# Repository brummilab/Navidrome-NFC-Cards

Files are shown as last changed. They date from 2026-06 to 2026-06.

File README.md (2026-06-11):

# Navidrome NFC Cards

Selbstgebaute Toniebox: NFC-Karte antippen → Musik vom eigenen [Navidrome](https://www.navidrome.org/)-Server läuft sofort.

Inspiriert von [gelly-nfc](https://github.com/Fingel/gelly-nfc), aber direkt gegen die Subsonic-API gebaut – ohne Desktop-Player, läuft headless auf dem Raspberry Pi.

---

## Architektur

```
┌──────────────────────────┐        Subsonic API        ┌─────────────────────┐
│      Raspberry Pi        │ ◄────────────────────────► │  Navidrome          │
│                          │                             │  (TrueNAS, NAS, …)  │
│  ┌────────────────────┐  │                             └─────────────────────┘
│  │  ACR1252U          │  │
│  │  NFC-Reader (USB)  │  │
│  └─────────┬──────────┘  │
│            │ Karte tippen │
│            ▼             │
│  ┌─────────────────────┐ │
│  │  NFC-Daemon         │─┼──► mpv ──► Lautsprecher
│  └─────────────────────┘ │
│  ┌─────────────────────┐ │
│  │  Web-UI  :8080      │ │  ← Karten verwalten
│  └─────────────────────┘ │
└──────────────────────────┘
```

---

## Hardware

| Teil | Modell |
|---|---|
| Einplatinen-Computer | Raspberry Pi 3 Model B (oder neuer) |
| NFC-Reader | [ACR1252U](https://www.acs.com.hk/en/products/342/acr1252u-usb-nfc-reader-iii-nfc-forum-certified-reader/) USB NFC Reader III |
| NFC-Karten | NTAG215 oder NTAG213 (ISO 14443-3A) |
| Lautsprecher | 3,5-mm-Klinke oder USB am Pi |
| Musik-Server | Navidrome (separat, z. B. auf TrueNAS) |

---

## Funktionsweise

Eine Karte kann auf zwei Arten einem Album / Track zugewiesen werden:

### A) Karte direkt beschreiben *(empfohlen)*

Der Text `album:abc123` wird als NDEF-Record direkt auf den Chip geschrieben.  
→ Karte ist **selbst-beschreibend**, kein DB-Eintrag nötig, kompatibel mit [gelly-nfc](https://github.com/Fingel/gelly-nfc).

### B) UID-Mapping via Web-UI

Die Karten-UID wird in einer lokalen SQLite-Datenbank einem Navidrome-Eintrag zugeordnet.  
→ Karte muss **nicht** beschrieben werden.

Beim Antippen wird immer zuerst **A** versucht, dann **B**.

---

## Installation

### 1. System-Pakete

```bash
sudo apt update
sudo apt install pcscd libpcsclite-dev mpv git python3-pip python3-venv
sudo systemctl enable --now pcscd
```

### 2. User-Rechte für NFC-Reader

```bash
sudo usermod -aG plugdev $USER
newgrp plugdev   # oder neu einloggen
```

### 3. Projekt einrichten

```bash
git clone https://github.com/brummilab/navidrome-nfc-cards.git
cd navidrome-nfc-cards

python3 -m venv .venv
source .venv/bin/activate
pip install -r requirements.txt
```

### 4. Konfiguration

```bash
cp config.example.yaml config.yaml
nano config.yaml
```

Mindest-Konfiguration:

```yaml
navidrome:
  url: http://192.168.1.100:4533   # IP des Navidrome-Servers
  username: dein-user
  password: dein-passwort
```

### 5. Starten

```bash
# Terminal 1 – Web-UI  →  http://raspberrypi:8080
python -m src.web.app

# Terminal 2 – NFC-Daemon
python -m src.run_daemon
```

---

## Erste Karte beschreiben

```bash
# 1. Reader prüfen
python -m src.card_writer list-readers
# [0] ACS ACR1252 Dual Reader PICC 0

# 2. Navidrome-Album-ID herausfinden
#    → Navidrome Web-UI öffnen → Album anklicken → URL ablesen:
#    http://navidrome:4533/app/#/album/abc123def456
#                                        ^^^^^^^^^^^^^ das ist die ID

# 3. Karte beschreiben (Reader anschließen, Karte drauflegen)
python -m src.card_writer write "album:abc123def456"

# 4. Inhalt prüfen
python -m src.card_writer read-ndef
# UID:  AA:BB:CC:DD
# NDEF: album:abc123def456
```

Unterstützte Typen:

```bash
python -m src.card_writer write "album:<id>"
python -m src.card_writer write "track:<id>"
python -m src.card_writer write "playlist:<id>"
python -m src.card_writer write "artist:<id>"
```

---

## Web-UI

`http://raspberrypi:8080`

| Seite | Funktion |
|---|---|
| **Karten** | Übersicht aller UID-Mappings mit Cover |
| **Scannen** | Karte antippen → UID anzeigen |
| **Musik** | Navidrome durchsuchen, UID per Klick zuweisen |

---

## Autostart (systemd)

```bash
# Daemon-Service
sudo tee /etc/systemd/system/navidrome-nfc-daemon.service > /dev/null << 'EOF'
[Unit]
Description=Navidrome NFC Daemon
After=network.target pcscd.service

[Service]
User=pi
WorkingDirectory=/home/pi/navidrome-nfc-cards
ExecStart=/home/pi/navidrome-nfc-cards/.venv/bin/python -m src.run_daemon
Restart=on-failure
RestartSec=5

[Install]
WantedBy=multi-user.target
EOF

# Web-UI-Service
sudo tee /etc/systemd/system/navidrome-nfc-web.service > /dev/null << 'EOF'
[Unit]
Description=Navidrome NFC Web-UI
After=network.target

[Service]
User=pi
WorkingDirectory=/home/pi/navidrome-nfc-cards
ExecStart=/home/pi/navidrome-nfc-cards/.venv/bin/python -m src.web.app
Restart=on-failure
RestartSec=5

[Install]
WantedBy=multi-user.target
EOF

sudo systemctl enable --now navidrome-nfc-daemon
sudo systemctl enable --now navidrome-nfc-web
```

---

## Gehäuse (3D-Druck)

Im Ordner `design/` liegt eine parametrische [OpenSCAD](https://openscad.org/)-Datei für ein Gehäuse im Toniebox-Stil:

- **Unterteil** ([`design/unterteil.stl`](design/unterteil.stl)): reader-breit (103 × 67 mm). Pi 180° gedreht, USB-Seite mit 10 mm Abstand zur Wand – genug Platz, damit das feste USB-Kabel des NFC-Readers komplett im Gehäuse an einen USB-Port des Pi angeschlossen werden kann (kein Wanddurchbruch dafür nötig). Einziger Wanddurchbruch: Stromanschluss in der Rückwand fürs Pi-Netzteil. Lüftungsschlitze links und rechts (je 4 Stück), läuft über WLAN. Pi auf 4 Abstandshaltern (M2.5).
- **Deckel** ([`design/deckel.stl`](design/deckel.stl)): gleichmäßig breit (108 × 72 mm), hält den ACR1252U *face-up* in einer Mulde. Der Reader ruht auf einer umlaufenden Neck-Auflage-Leiste, das Dach hält ihn nach oben. Karte oben drauflegen → NFC liest durch 1,5 mm Dach. Ein Kabel-Kanal an einer Ecke der Reader-Mulde führt das feste USB-Kabel des Readers nach unten ins Gehäuseinnere zum Pi. Der Deckel stülpt sich mit einem Rock 9 mm über das Unterteil.

Maße nach Datenblatt:

| Teil | Maß |
|---|-----|
| ACR1252U | 98 × 65 × 12,8 mm |
| Pi 3B Platine | 85 × 56 mm |
| Pi Montagelöcher | Rechteck 58 × 49 mm, 3,5 mm vom Rand (M2.5) |

### Dateien

| Datei | Zweck |
|---|---|
| `design/unterteil.stl` · `design/deckel.stl` | **Druckfertig** – direkt in den Slicer laden |
| `design/gehaeuse.scad` | Parametrische Quelle (OpenSCAD) |
| `design/build_stl.py` | STL neu erzeugen ohne OpenSCAD (`pip install numpy scipy trimesh manifold3d`) |
| `design/DRUCKANLEITUNG.md` | Schritt-für-Schritt-Anleitung für den **Bambu Lab P1S** |

> **Wichtig:** Der Deckel wird mit dem **Dach nach unten** gedruckt (Details in der Druckanleitung) – sonst wäre Support nötig.

### Zusammenbau

1. **Pi einsetzen**: Raspberry Pi **180° gedreht** (USB-Ports zeigen nach links, 10 mm Platz zur Wand) mit 4× M2.5-Schrauben auf die Abstandshalter schrauben.
2. **Reader einlegen**: ACR1252U von unten in die Deckel-Mulde legen (Geräteoberseite Richtung Dach). Der Reader ruht auf der umlaufenden Neck-Leiste, das Dach hält ihn nach oben. Das feste USB-Kabel durch den Kabel-Kanal an der Mulden-Ecke nach unten ins Gehäuseinnere führen.
3. **Kabel anschließen**: Im Inneren das USB-Kabel des Readers in einen USB-Port des Pi einstecken (Platz dafür ist links neben dem Pi).
4. **Schließen**: Deckel über das Unterteil stülpen – der Rock greift 9 mm über die Wände und zentriert alles. Das Stromkabel des Pi durch den Durchbruch in der Rückwand anschließen.

**Karte abspielen:** NFC-Karte oben auf den Deckel legen – der Reader liest durch das 1,5 mm dünne Dach (Lesedistanz lt. Datenblatt bis 50 mm).

---

## Docker (alternativ)

```bash
cp config.example.yaml config.yaml
docker compose up -d
```

> Der `reader`-Service benötigt USB-Zugriff (`privileged: true` in `docker-compose.yml`).  
> Auf dem Raspberry Pi ist das native Setup unkomplizierter.

---

## Konfigurationsreferenz

| Option | Standard | Beschreibung |
|---|---|---|
| `navidrome.url` | – | URL des Navidrome-Servers |
| `navidrome.username` | – | Benutzername |
| `navidrome.password` | – | Passwort |
| `playback.mode` | `mpv` | `mpv` = lokal auf Pi · `jukebox` = serverseitig |
| `playback.mpv_options` | `[]` | z. B. `["--volume=80"]` |
| `nfc.reader_index` | `0` | Index des Readers (siehe `list-readers`) |
| `nfc.debounce_seconds` | `5` | Selbe Karte nicht öfter als alle X Sekunden triggern |
| `web.port` | `8080` | Port der Web-UI |
| `data.db_path` | `data/mappings.db` | Pfad zur SQLite-Datenbank |

Umgebungsvariablen überschreiben `config.yaml`:  
`NAVIDROME_URL` · `NAVIDROME_USERNAME` · `NAVIDROME_PASSWORD` · `WEB_SECRET_KEY`

---

## Projektstruktur

```
src/
  config.py        Config-Loader (YAML + Env-Vars)
  navidrome.py     Subsonic API Client
  mappings.py      SQLite UID-Mapping
  player.py        Wiedergabe via mpv oder Jukebox
  nfc_reader.py    NFC-Daemon (CardMonitor, event-driven)
  card_writer.py   CLI: UIDs lesen, NDEF schreiben/lesen
  run_daemon.py    Entry Point Daemon
  web/
    app.py         Flask Web-UI
    templates/     Jinja2 Templates (Bootstrap 5)
design/
  gehaeuse.scad    3D-Druck Gehäuse (OpenSCAD)
```

---

## Abhängigkeiten

| Paket | Zweck |
|---|---|
| `pyscard` | PC/SC Zugriff auf den NFC-Reader |
| `ndeflib` | NDEF Record Encoding/Decoding |
| `flask` | Web-UI |
| `requests` | Navidrome Subsonic API |
| `pyyaml` | Konfigurationsdatei |
| `mpv` *(System)* | Lokale Audio-Wiedergabe |
| `pcscd` *(System)* | PC/SC Daemon |

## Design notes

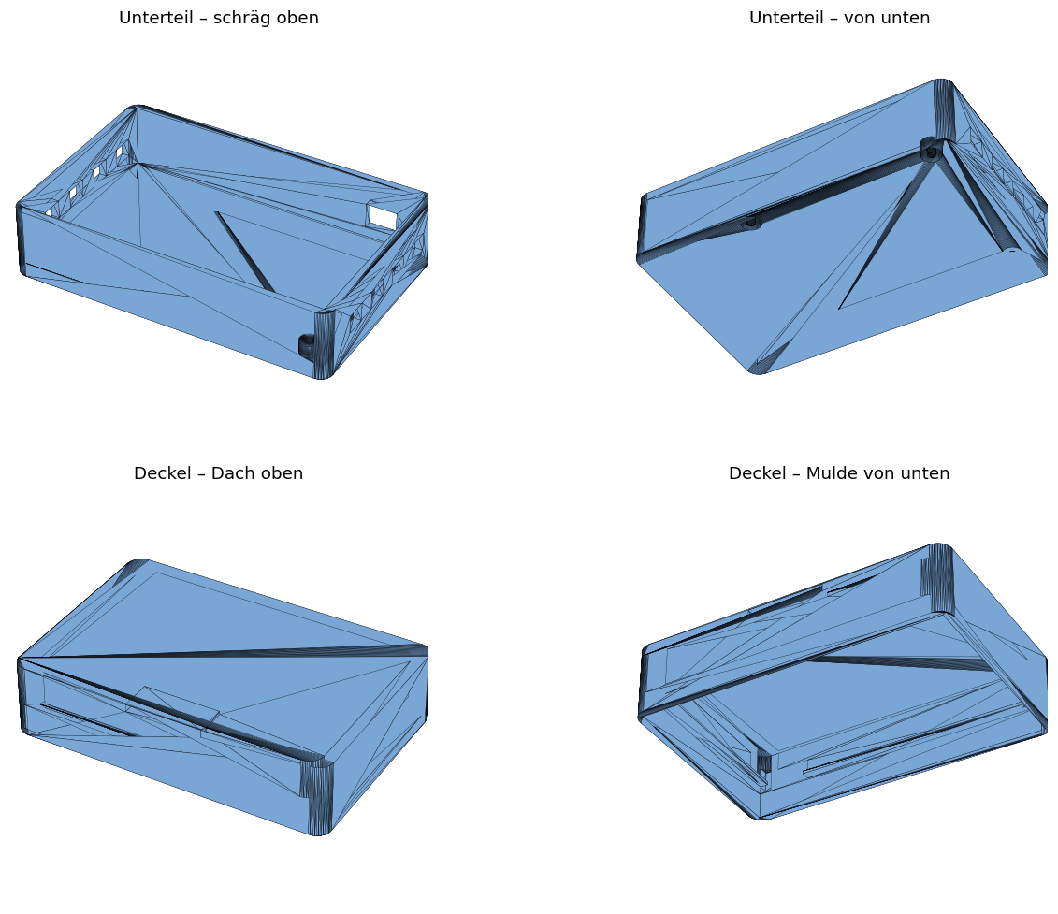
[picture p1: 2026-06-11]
design/preview.png

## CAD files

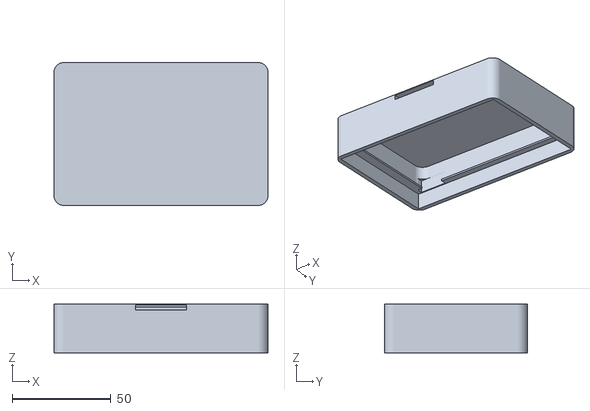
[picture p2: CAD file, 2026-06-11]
design/deckel.stl
108.4 x 72.4 x 24.8

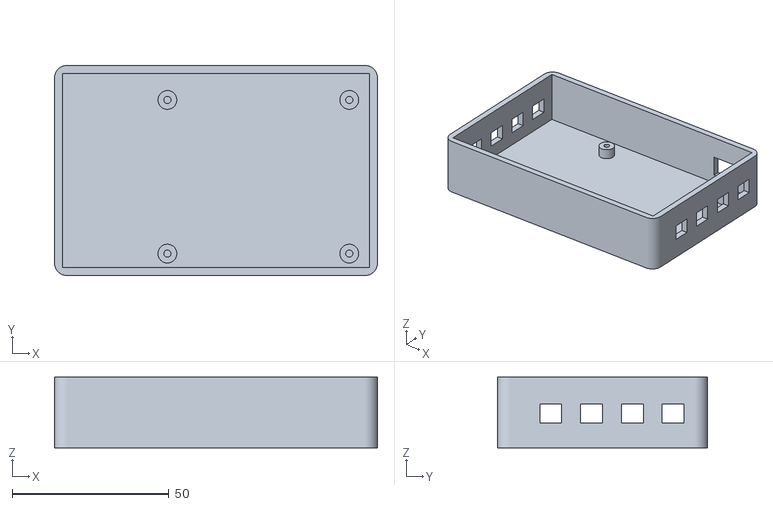
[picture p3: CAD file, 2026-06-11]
design/unterteil.stl
103.0 x 67.0 x 22.5

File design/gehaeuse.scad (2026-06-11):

// ============================================================
//  Navidrome NFC Box  ·  v7
//  Raspberry Pi 3 Model B (v1.2)  +  ACR1252U NFC-Reader
// ============================================================
//  Konzept (Toniebox-Stil):
//    · Unterteil : Breite = Reader-Breite → gleichmäßige Optik.
//                  Pi zentriert auf Abstandshaltern, Anschlüsse
//                  liegen bündig an den Wänden.
//    · Deckel    : Gleich breit wie Unterteil (nur kleiner Rand-
//                  Überstand wie ein klassischer Deckel). Hält den
//                  ACR1252U face-up in einer Mulde. Reader ruht auf
//                  einer umlaufenden Auflage-Leiste (Hals enger als
//                  Reader); Dach hält ihn nach oben.
//                  Karte oben auflegen → NFC liest durch 1.5 mm Dach.
//
//  ── Bambu Lab P1S – Druckeinstellungen ──────────────────────
//    Filament : PLA Basic  oder  PETG HF (steifer/wärmefester)
//    Profil   : 0.20 mm Standard · 3 Wände · 20 % Gyroid
//    Support  : KEINER nötig
//
//  Druck-Ausrichtung (wichtig, sonst Support nötig!):
//    · Unterteil : Boden aufs Druckbett (offene Seite nach oben)
//    · Deckel    : DACH (glatte Oberseite) aufs Druckbett,
//                  Rock zeigt nach OBEN  →  keine Brücken, kein Support
//
//  STL-Export: PART = "bottom" bzw. "lid" → F6 → als STL exportieren.
//
//  ►►  Mit (*) markierte Port-Maße am eigenen Pi prüfen!  ◄◄
// ============================================================

$fn = 64;
PART = "both";          // "bottom" | "lid" | "both"


// ── Wandstärken / Spiel ──────────────────────────────────────
WALL  = 2.5;
FLOOR = 2.5;
TOP   = 1.5;            // Deckel-Dach (NFC liest hindurch!)
GAP   = 0.2;            // Spiel Deckel ↔ Unterteil (P1S sehr präzise)


// ── Raspberry Pi 3 Model B ───────────────────────────────────
PI_W   = 85;
PI_D   = 56;
PI_PCB = 1.4;

// Montagelöcher: Rechteck 58 × 49 mm, 3.5 mm vom Rand (*)
PI_HX1 = 23.5;  PI_HX2 = 81.5;   // 180° flip: HX gespiegelt
PI_HY1 = 3.5;   PI_HY2 = 52.5;

STAND_H  = 4.0;
STAND_OD = 6.0;
STAND_ID = 2.3;        // M2.5 selbstschneidend


// ── ACR1252U NFC-Reader ──────────────────────────────────────
RDR_W = 98;
RDR_D = 65;
RDR_H = 12.8;          // lt. Datenblatt
RDR_R = 5;


// ── UNTERTEIL (reader-breit, Pi zentriert) ───────────────────
INNER_W = 98;          // = Reader-Breite → gleichmäßige Optik
INNER_D = 62;          // Pi 56 + ~3 mm Spiel je Seite
INNER_H = 20;          // Platz für höchste Bauteile (USB/LAN ~13.5)

OUTER_W = INNER_W + 2*WALL;     // 103
OUTER_D = INNER_D + 2*WALL;     // 67
OUTER_H = FLOOR + INNER_H;      // 22.5

PI_X = 10.0;                        // USB-Ports 10 mm von linker Wand: Platz fürs Reader-Kabel
PI_Y = 1.0;                         // Stecker zeigen jetzt nach hinten → Luft dort nötig
OX = WALL + PI_X;                   // 4.5
OY = WALL + PI_Y;                   // 3.5
PCB_TOP = FLOOR + STAND_H + PI_PCB;   // 7.9


// ── DECKEL (gleichmäßiger Kasten mit Neck-Auflage) ───────────
SKIRT_H   = 10.0;     // Höhe bis Mulden-/Leistenboden
NECK_H    = 1.0;      // dünnes Band der Auflage-Leiste
ENGAGE    = SKIRT_H - NECK_H;   // 9 mm: so tief greift der Rock über die Box
SKIRT_T   = 2.5;
RDR_POCKET = RDR_H + 0.5;       // 13.3  Muldentiefe (Reader + Luft)

pocket_w    = RDR_W + 1;                        // 99  Reader-Mulde (Spiel)
pocket_d    = RDR_D + 1;                        // 66
skirt_cav_w = OUTER_W + 2*GAP;                  // 103.4  Unterteil rutscht rein
skirt_cav_d = OUTER_D + 2*GAP;                  // 67.4
neck_w      = RDR_W - 5;                        // 93  < Reader → Leiste
neck_d      = RDR_D - 5;                        // 60

LID_W = skirt_cav_w + 2*SKIRT_T;               // 108.4
LID_D = skirt_cav_d + 2*SKIRT_T;               // 72.4
LID_H = SKIRT_H + RDR_POCKET + TOP;            // 24.8

// Querschnitt Deckel (Einbaulage – Dach oben, Rock unten):
//
//   ┌──────── Karte drauflegen ────────┐  z = LID_H (24.8)
//   │  Dach 1.5 mm  (NFC liest durch)  │
//   │ ┌──────────────────────────────┐ │  Reader-Mulde
//   │ │      ACR1252U  (face up)     │ │  (RDR_POCKET tief)
//   │ ╞══╡ Auflage-Leiste (Neck) ╞══╡ │  z = SKIRT_H (10)
//   │ │     Rock-Hohlraum            │ │  ← Unterteil rutscht hier rein
// ──┘ └──────────────────────────────┘ └──  z = 0  (Rock-Unterkante)


// ── Hilfsfunktionen ──────────────────────────────────────────

module rbox(w, d, h, r = 4) {
    r_ = min(r, w/2 - 0.01, d/2 - 0.01);
    linear_extrude(height = h)
        hull() {
            translate([r_,    r_   ]) circle(r = r_);
            translate([w-r_,  r_   ]) circle(r = r_);
            translate([r_,    d-r_ ]) circle(r = r_);
            translate([w-r_,  d-r_ ]) circle(r = r_);
        }
}

module standoff(h) {
    difference() {
        cylinder(d = STAND_OD, h = h);
        translate([0, 0, -0.1]) cylinder(d = STAND_ID, h = h + 0.2);
    }
}


// ── UNTERTEIL ────────────────────────────────────────────────
module bottom() {
    difference() {
        rbox(OUTER_W, OUTER_D, OUTER_H, r = 4);

        // Innenraum
        translate([WALL, WALL, FLOOR])
            cube([INNER_W, INNER_D, OUTER_H]);

        // ── HINTEN (Y=OUTER_D): Stromanschluss (Pi 180° gedreht) ──
        translate([OX + PI_W - 15.6, OUTER_D - WALL - 0.1, PCB_TOP - 2])
            cube([10, WALL + 0.2, 8]);

        // ── Lüftungsschlitze linke + rechte Wand ─────────────
        for (i = [0:3]) {
            translate([-0.1, OUTER_D/2 - 20 + i*13, PCB_TOP])
                cube([WALL + 0.2, 7, 6]);
            translate([OUTER_W - WALL - 0.1, OUTER_D/2 - 20 + i*13, PCB_TOP])
                cube([WALL + 0.2, 7, 6]);
        }
    }

    // Abstandshalter (0.5 mm in den Boden → sauberer Union)
    sz = FLOOR - 0.5;
    sh = STAND_H + 0.5;
    translate([OX + PI_HX1, OY + PI_HY1, sz]) standoff(sh);
    translate([OX + PI_HX2, OY + PI_HY1, sz]) standoff(sh);
    translate([OX + PI_HX1, OY + PI_HY2, sz]) standoff(sh);
    translate([OX + PI_HX2, OY + PI_HY2, sz]) standoff(sh);
}


// ── DECKEL ───────────────────────────────────────────────────
module lid() {
    px = (LID_W - pocket_w) / 2;       // Mulde zentriert
    py = (LID_D - pocket_d) / 2;
    sx = (LID_W - skirt_cav_w) / 2;    // Rock-Hohlraum zentriert
    sy = (LID_D - skirt_cav_d) / 2;
    nx = (LID_W - neck_w) / 2;         // Hals (Auflage-Leiste)
    ny = (LID_D - neck_d) / 2;

    difference() {
        rbox(LID_W, LID_D, LID_H, r = 5);

        // 1) Rock-Hohlraum (von unten): Unterteil schiebt sich hinein
        translate([sx, sy, -0.1])
            cube([skirt_cav_w, skirt_cav_d, ENGAGE + 0.1]);

        // 2) Hals-Aussparung (Auflage-Leiste bleibt stehen)
        translate([nx, ny, ENGAGE])
            cube([neck_w, neck_d, NECK_H + 0.01]);

        // 3) Reader-Mulde (über der Auflage-Leiste, Dach bleibt stehen)
        translate([px, py, SKIRT_H])
            rbox(pocket_w, pocket_d, RDR_POCKET + 0.01, r = RDR_R);

        // 4) Kabel-Slot: USB-Kabel links, direkt über den USB-Ports des Pi
        translate([5, ny + neck_d - 0.1, ENGAGE])
            cube([16, (py + pocket_d) - (ny + neck_d) + 0.2, SKIRT_H + 6 - ENGAGE]);

        // 5) Karten-Griffmulde im Dach (Daumen-Aussparung vorne, 0.4 mm Restwand)
        translate([LID_W/2 - 13, -0.1, LID_H - 3])
            cube([26, 11, 2.6]);
    }
}


// ── Ausgabe ──────────────────────────────────────────────────
if (PART == "bottom") {
    bottom();
} else if (PART == "lid") {
    lid();
} else {
    color("SteelBlue",     0.9) bottom();
    translate([LID_W + 20, 0, 0])
        color("LightSkyBlue", 0.9) lid();
}

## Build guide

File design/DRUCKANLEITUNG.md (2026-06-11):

# Druckanleitung – Navidrome NFC Box

Gehäuse für **Raspberry Pi 3 Model B** + **ACR1252U NFC-Reader**, ausgelegt für den **Bambu Lab P1S**.

Hier sind alle Infos, die du zum Drucken brauchst. Kein Vorwissen nötig.

---

## 1. Was wird gedruckt?

Zwei Teile – die STL-Dateien liegen im Ordner `design/`:

| Datei | Beschreibung | Maße | ca. Druckzeit* |
|---|---|---|---|
| [`unterteil.stl`](unterteil.stl) | Wanne für den Raspberry Pi | 103 × 67 × 22,5 mm | ~3 h |
| [`deckel.stl`](deckel.stl) | Deckel mit Aufnahme für den NFC-Reader | 108 × 72 × 25 mm | ~3,5 h |

\* bei 0,2 mm Schichthöhe / 20 % Infill – Bambu Studio zeigt den genauen Wert.

Beide Teile passen einzeln problemlos aufs Druckbett (256 × 256 mm).

---

## 2. Bambu Studio – Einstellungen

| Einstellung | Wert |
|---|---|
| Drucker | Bambu Lab P1S |
| Filament | **OVERTURE PLA+** – in Bambu Studio: Filament-Dropdown → „Generic PLA" wählen (oder OVERTURE direkt suchen) |
| Profil | **0.20 mm Standard** |
| Wandlinien (Wall loops) | **3** |
| Infill | **20 %**, Muster **Gyroid** |
| Support | **AUS** – wird nicht gebraucht |
| Brim | nur bei Haftproblemen (5 mm) |
| Platte | Textured PEI oder Engineering Plate |

> **PLA+ Tipps:**
> - Drucktemperatur: **220 °C** Düse, **60 °C** Bett (Bambu Studio setzt das automatisch beim Generic-PLA-Profil).
> - PLA+ haftet gut auf Textured PEI – kein Kleber nötig.
> - Das Regenbogen-Filament wechselt die Farbe kontinuierlich. Welche Farbe wo landet hängt vom Startpunkt auf der Spule ab – einfach drucken und überraschen lassen.

---

## 3. Ausrichtung auf dem Druckbett ← wichtig!

```
UNTERTEIL  → normal, Boden unten    DECKEL  → um 180° kippen, Dach unten!

┌───────────────┐                   ↑ Öffnung zeigt nach OBEN
│   offen oben  │                 ┌───────────────┐
│               │                 │   Rock/Rand   │
│   Boden unten │                 ├───────────────┤
└───────────────┘                 │   Dach        │  ← liegt auf dem Bett
  ↑ Boden aufs Bett               └───────────────┘
```

- **Unterteil**: einfach so laden, nichts drehen – flacher Boden liegt automatisch unten.
- **Deckel**: **um 180° kippen**, sodass die **glatte Oberseite (auf die später die NFC-Karte gelegt wird) auf dem Druckbett liegt** und die Öffnung nach oben zeigt.

> **Warum muss der Deckel gekippt werden?** Normal stehend wäre das Dach eine ~108 mm breite hängende Fläche → Support nötig. Gekippt gibt es nur einen kleinen inneren Überstand, den der P1S problemlos ohne Support überbrückt.
>
> Bonus: Die Dach-Oberfläche bekommt die schöne matte Textur des Druckbetts. Die NFC-Funktion wird dadurch nicht beeinträchtigt (das Dach ist nur 1,5 mm dick).

In Bambu Studio: Teil markieren → **R** (Rotieren) → X-Achse 180° → **P** (Drop to bed / auf Platte legen).

---

## 4. Drucken

1. Beide STLs in Bambu Studio laden (auf eine Platte oder nacheinander).
2. Deckel wie oben um 180° kippen, Unterteil bleibt wie es ist.
3. Einstellungen aus Schritt 2 wählen.
4. **Slicen** → Vorschau kurz prüfen → an den Drucker senden.

---

## 5. Nach dem Druck

- Kein Stützmaterial vorhanden – höchstens einen Brim-Rand abziehen, falls gesetzt.
- Deckel sollte sich mit leichtem Widerstand auf das Unterteil stülpen lassen. Falls er zu stramm oder zu locker sitzt, kurze Rückmeldung → ich passe die Toleranz an und schicke neue STLs.

> **Hinweis Zusammenbau** (falls du auch zusammenbaust):
> 1. Pi **180° gedreht** einsetzen – USB-Ports zeigen nach **links** (dort sind auch die Lüftungsschlitze, und 10 mm Platz für das Reader-Kabel).
> 2. NFC-Reader von unten in die Deckel-Mulde legen (glatte Seite Richtung Dach). Das **feste USB-Kabel** durch den Kabel-Kanal an der Mulden-Ecke nach unten ins Gehäuse führen und dort in einen USB-Port des Pi stecken.
> 3. Das Stromkabel des Pi durch den Durchbruch in der Rückwand anschließen.

Danke! 🙏

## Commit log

2026-05-28 Initial project setup: Navidrome NFC Cards
    NFC-Karten-System für Navidrome mit Web-UI, NFC-Daemon (ACR1252U/PC/SC),
    Subsonic API-Client, NTAG213-Writer und Docker Compose Setup.
    https://claude.ai/code/session_01QHQbYzvZM3NJKVoEKvfotM
2026-05-28 Add NDEF Text read/write; dual-mode card resolution
    - card_writer: schreibt NDEF Text Records (album:id format, kompatibel
    mit gelly-nfc); neuer read-ndef Befehl liest Karteninhalt
    - nfc_reader: liest zuerst NDEF vom Karten-Chip, fällt auf UID-DB zurück
    - requirements: ndeflib hinzugefügt
    - config: Raspberry Pi + TrueNAS Kommentare; Scan-UI zeigt beide Workflows
    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
2026-05-28 Vollständiges README: Architektur, Setup, systemd, CLI-Referenz
    Dokumentiert Raspberry Pi + TrueNAS Architektur, beide Karten-Workflows
    (NDEF schreiben vs. UID-Mapping), systemd Autostart und alle CLI-Befehle.
    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
2026-05-28 NTAG215/216 Kompatibilität: Kapazität aus CC lesen statt hardcoden
    Liest max_user_bytes aus dem Capability Container der Karte (CC[2]*8).
    Unterstützt jetzt NTAG213 (144B), NTAG215 (504B) und NTAG216 (888B).
    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
2026-05-28 3D-Druckgehäuse für Pi 3B + ACR1252U (OpenSCAD)
    Parametrisches Gehäuse: Pi im Unterteil auf Abstandshaltern,
    NFC-Reader eingelassen im Deckel, Port-Ausschnitte für alle
    relevanten Anschlüsse.
    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
    [gehaeuse.scad]
2026-05-28 Gehäuse v2: Manifold-Fehler behoben
    Entfernt den getrennten NFC-Rahmen (war Ursache für Volumes:3).
    Deckplatte jetzt 10.5mm dick (NFC_H+2) damit Einlass Boden hat.
    Lippe sauber als Hollow-Zylinder ohne überlappende Geometrie.
    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
    [gehaeuse.scad]
2026-05-28 Gehäuse v3: Manifold-Fix via 2D-hull + linear_extrude + Überlappungen
    rbox() nutzt jetzt 2D-hull(circles) + linear_extrude statt 3D-hull.
    Standoffs und Lippe 0.1mm in angrenzende Körper eingesenkt (coplanar-fix).
    PART-Variable zum einzelnen Exportieren der Teile als STL.
    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
    [gehaeuse.scad]
2026-05-28 Gehäuse v4: Außenrock statt Innenlippe, cube-Hohlraum, 0.5mm Überlappungen
    - Deckel sitzt jetzt ÜBER der Box (Außenrock), nicht mit Innenlippe
    - Rock-Hohlraum mit cube statt rbox → einfachere Geometrie, manifold-sicher
    - 0.5mm Überlappungen: Abstandshalter 0.5mm in Boden, Rock 0.5mm in Platte
    - Explizite standoff-Translate statt for-Schleife
    - Lüftungsschlitze an rechter Seitenwand (statt Boden)
    - NFC-Einlass-Boden bei z=2mm (LID_PLATE - NFC_H, klar über z=0)
    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
    [gehaeuse.scad]
2026-05-28 Gehäuse v5: komplett neu mit korrekten Maßen aus Datenblättern
    Recherche / korrigierte Maße:
    - ACR1252U: 98 × 65 × 12.8 mm (vorher fälschlich 8.5 mm Höhe)
    - Pi 3B Montagelöcher: Rechteck 58 × 49 mm, 3.5 mm Randabstand
    → (3.5,3.5) (61.5,3.5) (3.5,52.5) (61.5,52.5)
    - Pi 3B Portlayout: Power/HDMI/Audio an Längsseite,
    4×USB+Ethernet an Schmalseite, microSD gegenüber
    Neues Konzept (Toniebox-Stil):
    - Reader liegt face-up im Deckel, Karte oben drauflegen
    - NFC liest durch 1.5 mm Dach
    - Deckel stülpt sich mit 8 mm Außenrock über das Unterteil
    - Pi in Vorder-Rechts-Ecke → Anschlüsse bündig an den Wänden
    - Reader ruht auf Zwischenboden, Kabel-Durchführung nach unten
    - Mani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
    [gehaeuse.scad]
2026-05-28 Gehäuse v5.1: Bambu P1S Slicer-Hinweise, GAP auf 0.2 mm
    - Druckanleitung für Bambu Studio ergänzt (Profil, Wände, Infill,
    Druckreihenfolge, kein Support nötig)
    - GAP 0.4 → 0.2 mm (P1S sehr maßgenau, engeres Spiel reicht)
    - Materialempfehlung PLA/PETG
    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
    [gehaeuse.scad]
2026-05-28 README: Gehäuse-Abschnitt erweitert + P1S-Druckanleitung
    - README Gehäuse-Sektion: neues Toniebox-Konzept, Datenblatt-Maße,
    STL-Export pro Teil, Verweis auf Druckanleitung
    - Neue design/DRUCKANLEITUNG.md: eigenständige Schritt-für-Schritt-
    Anleitung für den Bambu Lab P1S (für Drucker-Freund ohne Vorwissen)
    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
2026-05-28 Gehäuse v6: getrennte Footprints, druckfertige STLs, SD-Zugang gelöst
    Problem v5: Reader (98 mm) diktierte breiten Innenraum → Pi in Ecke
    geschoben → SD-Karte (links mittig) 15 mm von der Wand, nicht erreichbar.
    Außerdem hätte der Deckel-Vollboden eine ~94 mm Brücke (Support nötig).
    Lösung v6:
    - Unterteil schmal (94×65), exakt für den Pi → ALLE Anschlüsse bündig,
    inkl. microSD links mittig (laut Datenblatt-Layout)
    - Deckel breiter (104×71), überlappt das Unterteil mit 8 mm Rock
    - Reader-Halterung: ruht auf umlaufender Auflage-Leiste, Dach hält oben
    - Druck Dach-nach-unten → nur 2,3 mm Überhang, KEIN Support nötig
    Dateien:
    - design/build_stl.py: erzeugt STLs via tr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
    [deckel.stl, gehaeuse.scad, unterteil.stl]
2026-05-29 Gehäuse v7: reader-breites Unterteil, Neck-Auflage im Deckel
    Unterteil jetzt so breit wie der ACR1252U-Reader (103 × 67 mm) statt
    schmal für den Pi – gleichmäßigere Optik. Der Deckel verwendet eine
    umlaufende Neck-Leiste (statt der alten Kabel-Aussparung) als
    Auflage für den Reader; der Rock greift 9 mm über das Unterteil.
    gehaeuse.scad und build_stl.py sind wieder synchron (beide v7).
    Maße in README und DRUCKANLEITUNG aktualisiert.
    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
    [gehaeuse.scad]
2026-05-29 Fix: Griffmulde durchstach Deckel-Dach um 0,1 mm
    Höhe der Daumen-Aussparung von 3,1 auf 2,9 mm reduziert.
    Zuvor: Mulde endete bei z=24,9 mm, Deckel-Dach bei z=24,8 mm
    → 0,1 mm Loch in der Dach-Oberfläche.
    Jetzt: Mulde endet bei z=24,7 mm, 0,1 mm Sicherheitsabstand.
    STLs neu erzeugt (beide watertight).
    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
    [deckel.stl, gehaeuse.scad, unterteil.stl]
2026-05-29 Kabel-Slot für Reader-USB-Kabel wieder eingefügt
    Beim v7-Umbau (Neck-Auflage) war die Kabel-Aussparung verloren
    gegangen → Reader-Kabel hätte keinen Weg nach unten gehabt.
    Jetzt: 16 mm breiter Slot mittig in der hinteren Auflage-Leiste,
    durch den das feste USB-Kabel der ACR1252U nach unten zum Pi läuft.
    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
    [deckel.stl, gehaeuse.scad]
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2026-05-30 Fix: Pi zur USB/LAN-Wand schieben (2 mm Luft statt zentriert)
    Durch die v7-Verbreiterung auf Reader-Breite (98 mm Innenraum)
    wurde PI_X auf (INNER_W-PI_W)/2 = 6.5 mm gesetzt (Pi zentriert).
    Das ließ 6.5 mm Luft zwischen Pi-Kante und rechter Wand →
    USB/LAN-Ports saßen 4.5 mm hinter der Wandöffnung, unzugänglich.
    Fix: PI_X = INNER_W - PI_W - 2.0 = 11.0 mm → 2 mm Luft zur
    USB/LAN-Wand (wie in v6). Links bleiben 11 mm ungenutzter Raum.
    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
    [gehaeuse.scad, unterteil.stl]
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2026-05-31 Fix: PI_Y +2 mm – Stecker standen vorne über (Testdruck)
    Erster Testdruck zeigte: Pi-Stecker (Power/HDMI/Audio) ragten
    über die Vorderwand hinaus. PI_Y von 3 auf 5 mm erhöht →
    Pi sitzt 5 mm von der Innenwand entfernt, Steckerspitzen
    liegen jetzt ~3.5 mm hinter der Außenwand. Kein Überstand mehr.
    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
    [gehaeuse.scad, unterteil.stl]
2026-05-31 microSD-Aussparung entfernt (hinfällig)
    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
    [gehaeuse.scad, unterteil.stl]
2026-05-31 Alle Port-Ausschnitte entfernt, nur Lüftungsschlitze bleiben
    Power, HDMI, Audio, USB/LAN – alle weg. Gehäuse ist jetzt
    geschlossen bis auf die 4 Lüftungsschlitze hinten.
    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
    [gehaeuse.scad, unterteil.stl]
2026-05-31 Pi 180° gedreht, Lüftung links+rechts, Kabel-Slot nach links
    - Pi 180° gedreht: USB-Ports jetzt links (2 mm von linker Wand),
    Abstandshalter-Positionen gespiegelt (HX1=23.5, HX2=81.5)
    - Lüftungsschlitze von hinten nach links+rechts verschoben
    (je 4 Schlitze, 7×6 mm, gleichmäßig verteilt)
    - Kabel-Slot im Deckel nach links (X=5–21 mm) verschoben,
    liegt jetzt direkt über den USB-Ports des Pi
    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
    [deckel.stl, gehaeuse.scad, unterteil.stl]
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2026-05-31 Stromanschluss-Ausschnitt an Hinterwand hinzugefügt
    Pi ist 180° gedreht → micro-USB-Power sitzt jetzt hinten.
    Ausschnitt 10×8 mm an Y=OUTER_D (Hinterwand), gespiegelte
    X-Position: OX + PI_W - 15.6 = 73.9 mm.
    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
    [gehaeuse.scad, unterteil.stl]
2026-06-11 Mehr Platz für Reader-Kabel am Pi, Griffmulde-Restwand erhöht
    Pi rückt von 2mm auf 10mm Abstand zur linken Wand (USB-Seite) -
    genug Raum, um das feste USB-Kabel des NFC-Readers intern an
    den Pi anzuschließen. Nur das Stromkabel braucht den
    Wanddurchbruch. Griffmulden-Restwand im Deckel-Dach von 0.1mm
    auf 0.4mm erhöht, damit dort kein Loch mehr entsteht.
    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
    [deckel.stl, gehaeuse.scad, unterteil.stl]
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
